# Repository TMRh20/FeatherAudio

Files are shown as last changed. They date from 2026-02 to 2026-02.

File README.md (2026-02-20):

# FeatherAudio
Custom Circuit Board for Feather 52840

Designed by TMRh20, Sponsored by [PCBWay](https://pcbway.com)
<br>
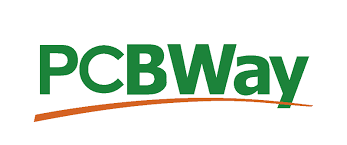
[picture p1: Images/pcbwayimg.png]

<br><br>
Requirements:<br>
2 x Custom Circuit Board <br>
2 x Feather 52840 based board (Feather 52840 Sense or Express) <br>
2 x Max98357A I2S Amplifier breakout <br>
2 x 4 to 8 Ohm Speaker (Gikfun 1.5" 4-Ohm, 3w, EK1794) <br>
2 x 2032 3.3v Coin Battery <br>
6 x AAA Battery <br>
(Optional) 2 x Micro-SD Card <br>
<br>
This custom circuit board was designed for basic prototyping via the AutoAnalogAudio library, however, it can be used
to create a custom walkie-talkie or intercom with range similar to Bluetooth. <br>

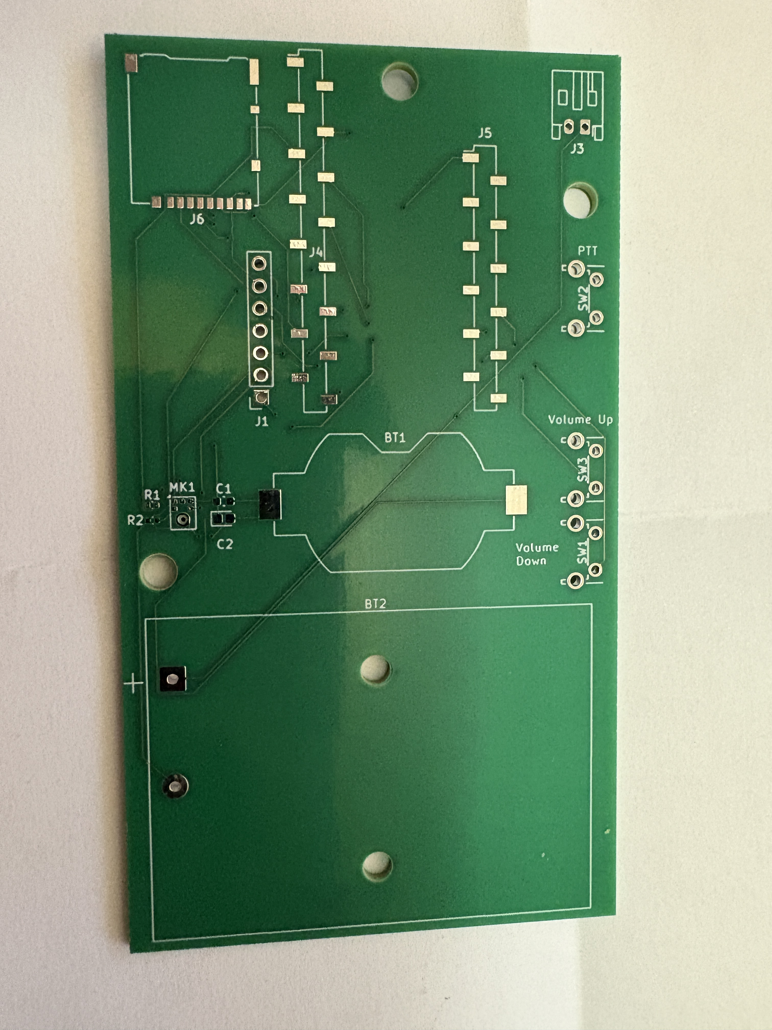
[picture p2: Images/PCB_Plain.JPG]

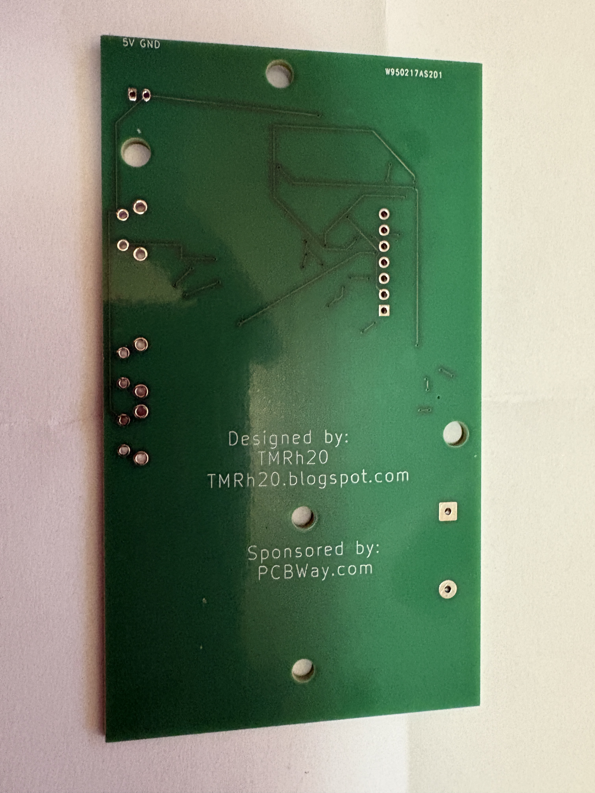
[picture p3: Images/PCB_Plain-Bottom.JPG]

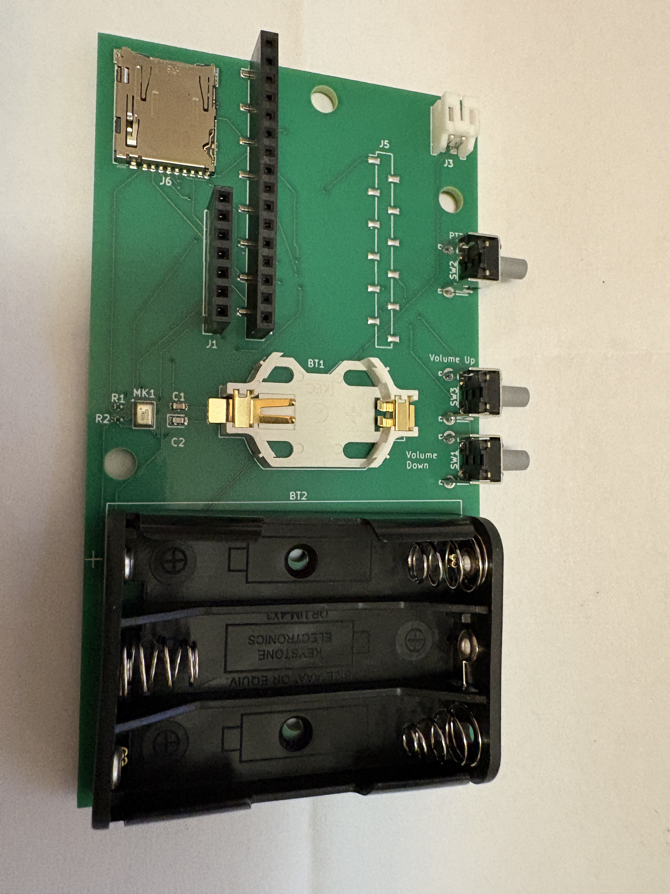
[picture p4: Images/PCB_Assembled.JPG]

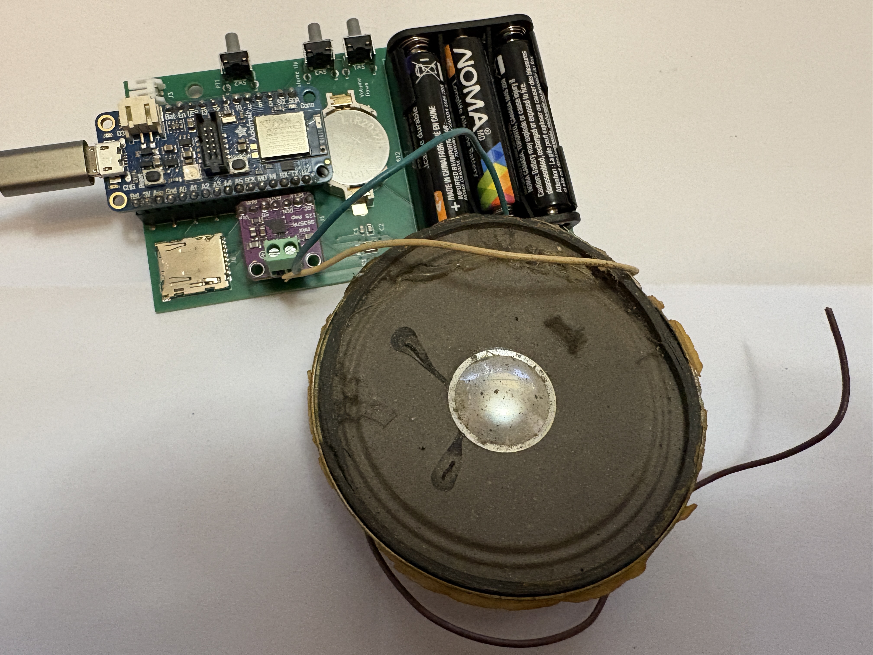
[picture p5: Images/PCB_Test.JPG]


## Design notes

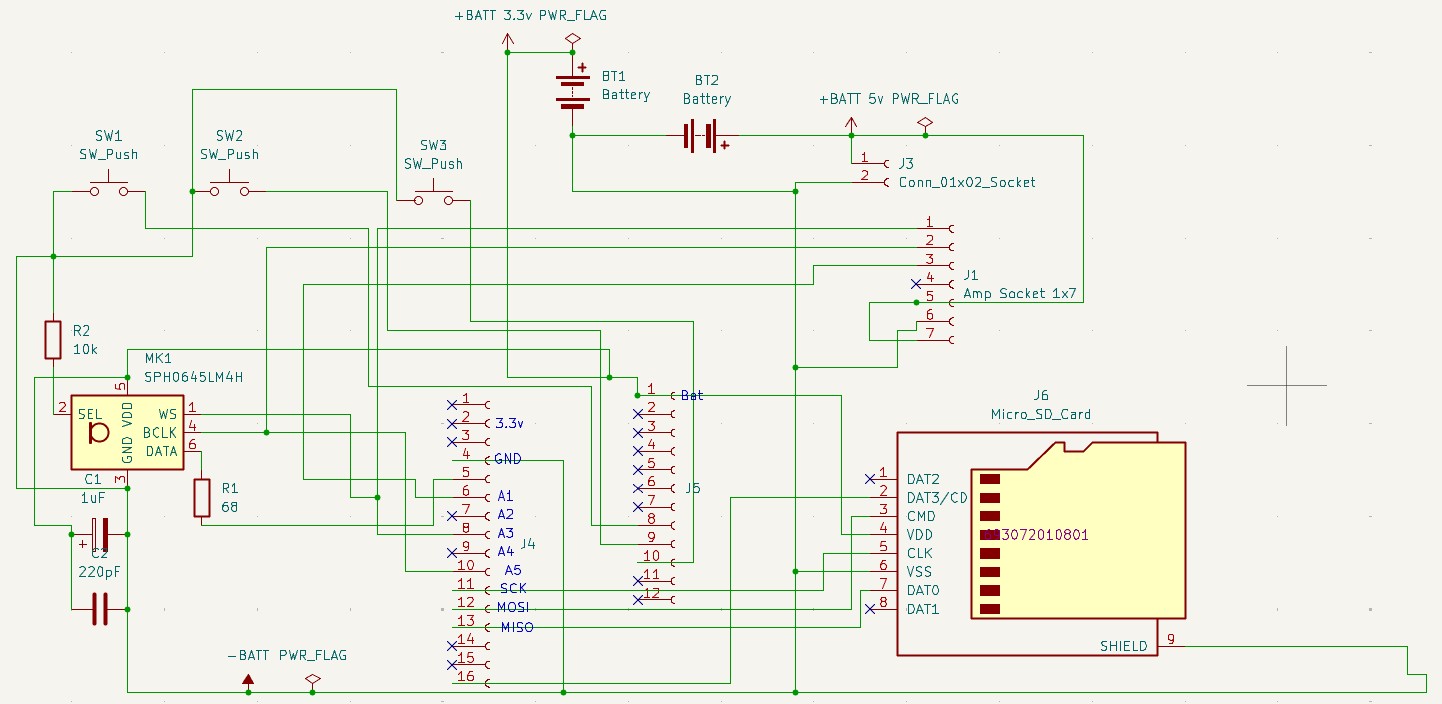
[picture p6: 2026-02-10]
Images/Schematic.jpg

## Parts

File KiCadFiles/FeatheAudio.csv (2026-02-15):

Reference | Qty | Value | DNP | Exclude from BOM | Exclude from Board | Footprint | Datasheet | Description | # | Part Number
BT1 | 1 | Battery |  |  |  | Battery:BatteryHolder_Keystone_1058_1x2032 | ~ | Holder Battery; Coin Battery; 1 Cell; Tab; Glass Filled LCP; 0.787 in. Dia. | 1 | 1058
BT2 | 1 | Battery |  |  |  | Battery:BatteryHolder_Keystone_2479_3xAAA | ~ | Cylindrical Battery Contacts, Clips, Holders & Springs 3AAA HOLDER PC MNT | 2 | 2479
C1 | 1 | 1uF |  |  |  | Capacitor_SMD:C_0603_1608Metric | ~ | 100V 1uF X7S å ¤10% 0805 Multilayer Ceramic Capacitors MLCC - SMD/SMT ROHS | 3 | GRM188D72A105KE01D（100V 1uF X7T 10% 0603）
C2 | 1 | 220pF |  |  |  | Capacitor_Tantalum_SMD:CP_EIA-1608-08_AVX-J | ~ | 0603 220 pF 50 V Â±1 % Tolerance C0G/NP0 SMT Multilayer Ceramic Chip Capacitor | 4 | VJ0603A221FXACW1BC
J1 | 1 | Amp Socket 1x7 |  |  |  | Connector_PinSocket_2.54mm:PinSocket_1x07_P2.54mm_Vertical | ~ | Btb Conn, Rcpt, 7Pos, 1Row, 2.54Mm Rohs Compliant: Yes |Wurth Elektronik 61300711821 | 5 | 61300711821
J3 | 1 | Conn_01x02_Socket |  |  |  | Connector_JST:JST_PH_S2B-PH-K_1x02_P2.00mm_Horizontal | ~ | Conn Shrouded Header (4 Sides) HDR 2 POS 2mm Solder RA Side Entry Thru-Hole Box | 6 | S2B-PH-K-S(LF)(SN)
J4 | 1 | XIAO LEFT |  |  |  | Connector_PinSocket_2.54mm:PinSocket_1x16_P2.54mm_Vertical_SMD_Pin1Left | ~ | THT Vertical Socket Header WR-PHD, Pitch 2.54 mm, Single Row, 16 pins | 7 | DS1023-16-1*16B81XBX1 work? https://www.tme.eu/en/details/ds1023-16-1x16tx1/pin-headers/connfly/ds1023-16-1-16b81xbx1/
J5 | 1 | XIAO RIGHT |  |  |  | Connector_PinSocket_2.54mm:PinSocket_1x12_P2.54mm_Vertical_SMD_Pin1Left | ~ | THT Vertical Socket Header WR-PHD, Pitch 2.54 mm, Single Row, 12 pins | 8 | 4217-CSHC121-1202A001C1AC-ND https://www.greenconn.com/Upload/Products/drawing-cshc121.pdf
J6 | 1 | Micro_SD_Card |  |  |  | Connector_Card:microSD_HC_Hirose_DM3AT-SF-PEJM5 | https://www.we-online.com/components/products/datasheet/693072010801.pdf | Conn, Memory Skt, Microsd, 8POS, Hinged Rohs Compliant: Yes | 9 | 693072010801
MK1 | 1 | SPH0645LM4H |  |  |  | Sensor_Audio:Knowles_SPH0645LM4H-6_3.5x2.65mm | https://www.knowles.com/docs/default-source/default-document-library/sph0645lm4h-1-datasheet.pdf | Knowles MEMS Microphone, 24-bit I2S, 65 dBA SNR, LGA-6 | 10 | SPH0645LM4H-1-8
R1 | 1 | 68 |  |  |  | Resistor_SMD:R_0402_1005Metric | ~ | Res Thick Film 2512 68 Ohm 5% 3W Â±200ppm/C Pad SMD T/R Automotive | 11 | FRC0402J680 TS（68R 5% 62.5mW 0402）
R2 | 1 | 10k |  |  |  | Resistor_SMD:R_0402_1005Metric | ~ | Precision resistor, SMD [TE Connectivity] SMF310KJT Precision resistor, SMD | 12 | RC0402FR-0710KL（0402 10K 1%）
SW1,SW2,SW3 | 3 | SW_Push |  |  |  | Button_Switch_THT:SW_Tactile_SPST_Angled_PTS645Vx83-2LFS | Switch Tactile N.O. SPST Round Button PC Pins 0.05A 12VDC 100000Cycle 1.96N Thru-Hole Bulk,~ | Switch Tactile N.O. SPST Round Button PC Pins 0.05A 12VDC 100000Cycle 1.96N Thru-Hole Bulk | 13 | Y97HS12A4VAFP

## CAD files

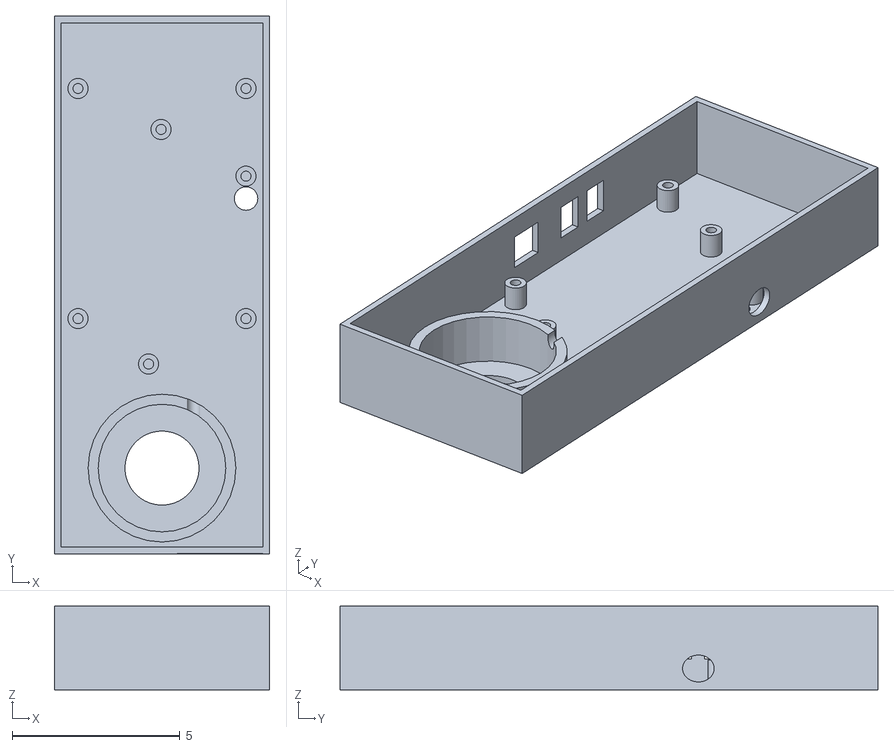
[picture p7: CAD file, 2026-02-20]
3D-Case/FeatherBaseV1.stl
6.40 x 16.0 x 2.50

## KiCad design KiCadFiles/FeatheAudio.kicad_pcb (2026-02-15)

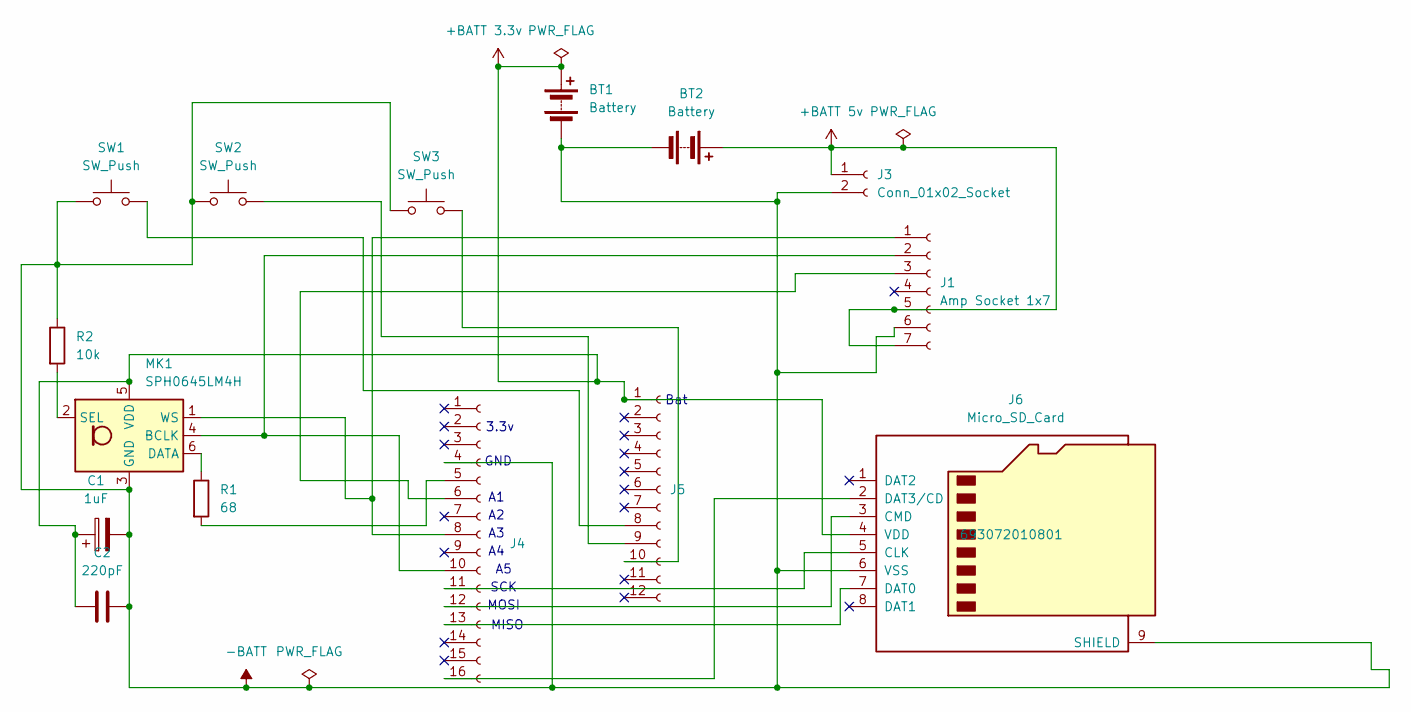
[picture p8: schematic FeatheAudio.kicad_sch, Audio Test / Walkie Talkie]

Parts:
BT1: Battery; BatteryHolder_Keystone_1058_1x2032; Part Number 1058
BT2: Battery; BatteryHolder_Keystone_2479_3xAAA; Part Number 2479
C1: 1uF; C_0603_1608Metric; Part Number GRM188D72A105KE01D（100V 1uF X7T 10% 060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
C2: 220pF; CP_EIA-1608-08_AVX-J; Part Number VJ0603A221FXACW1BC
J1: Amp Socket 1x7; PinSocket_1x07_P2.54mm_Vertical; Part Number 61300711821
J3: Conn_01x02_Socket; JST_PH_S2B-PH-K_1x02_P2.00mm_Horizontal; Part Number S2B-PH-K-S(LF)(SN)
J4: XIAO LEFT; PinSocket_1x16_P2.54mm_Vertical_SMD_Pin1Left; Part Number DS1023-16-1*16B81XBX1 work? https://www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
J5: XIAO RIGHT; PinSocket_1x12_P2.54mm_Vertical_SMD_Pin1Left; Part Number 4217-CSHC121-1202A001C1AC-ND https://ww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
J6: Micro_SD_Card; microSD_HC_Hirose_DM3AT-SF-PEJM5; Part Number 693072010801
MK1: SPH0645LM4H; Knowles_SPH0645LM4H-6_3.5x2.65mm; Part Number SPH0645LM4H-1-8
R1: 68; R_0402_1005Metric; Part Number FRC0402J680 TS（68R 5% 62.5mW 0402）
R2: 10k; R_0402_1005Metric; Part Number RC0402FR-0710KL（0402 10K 1%）
SW1, SW2, SW3: SW_Push; SW_Tactile_SPST_Angled_PTS645Vx83-2LFS; Part Number Y97HS12A4VAFP

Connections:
+BATT 3.3v: BT1.1 (+), C1.1, C2.1, J5.1, J6.4 (VDD), MK1.5 (VDD)
+BATT 5v: BT2.1 (+), J1.5, J1.7, J3.1
-BATT: BT1.2 (-), BT2.2 (-), C1.2, C2.2, J1.6, J3.2, J4.4, J6.6 (VSS), J6.9 (SHIELD), MK1.3 (GND), R2.1, SW1.1, SW2.1, SW3.1
unnamed: J1.1, J4.8, MK1.1 (WS)
unnamed: J1.2, J4.10, MK1.4 (BCLK)
unnamed: J1.3, J4.6
unnamed: J4.5, R1.2
unnamed: J4.11, J6.5 (CLK)
unnamed: J4.12, J6.3 (CMD)
unnamed: J4.13, J6.7 (DAT0)
unnamed: J4.16, J6.2 (DAT3/CD)
unnamed: J5.8, SW1.2
unnamed: J5.9, SW2.2
unnamed: J5.10, SW3.2
unnamed: MK1.6 (DATA), R1.1
unnamed: MK1.2 (SEL), R2.2

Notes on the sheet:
3.3v
MISO
SCK
GND
Bat
MOSI

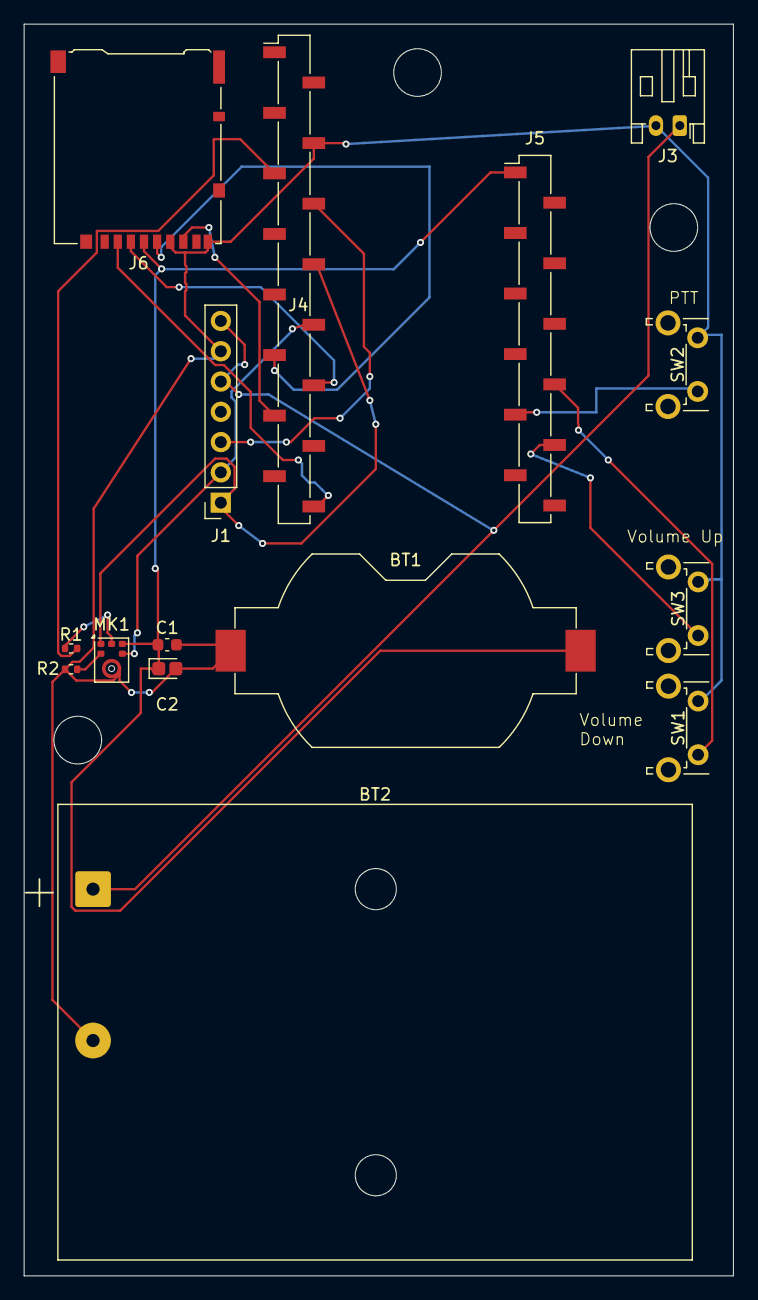
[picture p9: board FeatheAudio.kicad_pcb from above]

Board: 2 copper layers, 59.5 x 105.0 mm, 15 parts (0 on the bottom side), 16 nets.

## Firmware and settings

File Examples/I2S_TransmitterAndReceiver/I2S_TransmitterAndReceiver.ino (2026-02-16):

/** 
* Wireless Audio Transceiver
*
* This code allows users to create a wireless radio or intercomm using the custom PCB
* found at https://github.com/TMRh20/FeatherAudio
* 
* by TMRh20 2026
*/



#include <AutoAnalogAudio.h>
#include <nrf_to_nrf.h>

AutoAnalog aaAudio;
nrf_to_nrf radio;


#if defined(USE_TINYUSB)
// Needed for Serial.print on non-MBED enabled or adafruit-based nRF52 cores
#include "Adafruit_TinyUSB.h"
#endif

/**************** USER VARIABLES *************************/

#define AUDIO_DEBUG 1                // Set to 1 to print out values from the microphone
#define RADIO_CHANNEL 50             // Set the channel for the radio
volatile float volumeControl = 3.5;  // Default Volume level
uint32_t sampleRate = 32000;         // Either 16000 or 32000 supported

/*********************************************************/

#define BUFFER_SIZE 124
uint8_t address[6] = { "1Node" };
volatile bool micActive = false;
volatile bool rxToggled = false;
volatile bool txToggled = false;

/*****************************************/

void volUp() {
  volumeControl += 0.5;         // Raise Volume
  if (digitalRead(9) == LOW) {  // If both pins are pressed, volDown pressed first
    micActive = true;           // Enable the microphone until PTT is pressed
    setupInput();               // Setup audio for the microphone
  }
}
/*****************************************/
void volDown() {
  volumeControl -= 0.5;       // Lower volume
  if (volumeControl < 0.1) {  // If volume setting too low set to 0.0
    volumeControl = 0.0;
  }
}

/*****************************************/

void ptt() {

  if (digitalRead(6) == LOW) {  // If PTT button pressed
    micActive = true;           // Enable I2S microphone
    rxToggled = true;           // Only enable microphone once via this variable

  } else {
    micActive = false;  // Enable I2s amplifier output
    txToggled = true;   // Only enable output once via this variable
  }
}

/*****************************************/

void setupOutput() {
  aaAudio.manualI2S = false;             // Use internal I2S timers for I2S
  aaAudio.begin(0, 2);                   // Setup aaAudio using I2S amplifier output
  aaAudio.dacBitsPerSample = 16;         // 16-bit samples output to I2S
  aaAudio.setSampleRate(sampleRate, 0);  // 32 or 16kHz
  radio.startListening();                // Start the radio in listen mode
}

/*****************************************/

void setupInput() {
  aaAudio.manualI2S = true;              // Use PWM to drive the I2S signal
  aaAudio.begin(2, 0);                   // Enable I2S microphone input
  aaAudio.adcBitsPerSample = 24;         // Needs to be 24 bits for the onboard microphone
  aaAudio.setSampleRate(sampleRate, 0);  // 32 or 16kHz
  radio.stopListening();                 // Start the radio in tx mode
}

/*****************************************/

void setup() {

  Serial.begin(115200);
  radio.begin();  // General radio config
  radio.setChannel(RADIO_CHANNEL);
  radio.setPayloadSize(BUFFER_SIZE);
  radio.setAutoAck(0);
  radio.setDataRate(NRF_1MBPS);
  radio.openWritingPipe(address);
  radio.openReadingPipe(1, address);
  radio.startListening();

  pinMode(LED_BUILTIN, OUTPUT);  // LED toggles to red when data is received, off if no data
  digitalWrite(LED_BUILTIN, LOW);
  pinMode(6, INPUT_PULLUP);  // Enable PTT pin
  attachInterrupt(digitalPinToInterrupt(6), ptt, CHANGE);
  pinMode(9, INPUT_PULLUP);
  pinMode(5, INPUT_PULLUP);
  attachInterrupt(digitalPinToInterrupt(9), volDown, FALLING);  // Enable Volume pins
  attachInterrupt(digitalPinToInterrupt(5), volUp, FALLING);

  aaAudio.I2S_PIN_LRCK = 28;                // WS Pin: On the Feather 52840 Express or Sense, this is pin A3
  aaAudio.maxBufferSize = BUFFER_SIZE * 2;  // Set maxBufferSize to limit memory usage
  setupOutput();                            // Setup I2S audio output
}

/*****************************************/

int32_t audioBuffer[BUFFER_SIZE / 2];
uint32_t lastRadio = millis();

/*****************************************/

void loop() {

  if (micActive) {    // If the mic has been toggled on by the PTT or combination of LowVolume then HighVolume buttons
    if (rxToggled) {  // Only do this once per toggle
      setupInput();   // Configure I2S audio input
      rxToggled = false;
    }
    aaAudio.getADC(BUFFER_SIZE / 2);  // Get data from I2S mic, will get 18-bit samples in a 32-bit format, but output 16-bit samples over the radio

    uint16_t counter2 = 0;
    for (int i = 0; i < BUFFER_SIZE / 2; i++) {
      memcpy(&audioBuffer[i], &aaAudio.adcBuffer16[counter2], 4);  // Loop to copy data from 16-bit incoming buffer to a 32-bit integer buffer
      audioBuffer[i] >>= 2;                                        // Change from 18-bit to 16-bit
      memcpy(&aaAudio.dacBuffer16[i], &audioBuffer[i], 2);         // Copy to 16-bit output buffer from 32-bit format
      counter2 += 2;
    }
#if AUDIO_DEBUG > 0
    int16_t test = 0;
    memcpy(&test, &aaAudio.dacBuffer16[0], 2);
    Serial.print(test);
    Serial.print(",");
    Serial.print(-5000);
    Serial.print(",");
    Serial.println(5000);
#endif
    radio.startWrite(&aaAudio.dacBuffer16[0], BUFFER_SIZE, 1);  // Send 62 16-bit samples over the radio (124 bytes)

  } else {

    if (txToggled) {      // If I2S output has been toggled
      setupOutput();      // Setup I2S amplifier output
      txToggled = false;  // Only needs to be done once
    }
    if (radio.available()) {  // Check for incoming radio data

      radio.read(&aaAudio.dacBuffer16[0], BUFFER_SIZE);  // Read incoming radio data, 124 bytes or 62 16-bit samples

      for (int i = 0; i < BUFFER_SIZE / 2; i++) {  // Loop for the number of actual samples
        int16_t test = aaAudio.dacBuffer16[i];     // Adjust volume for incoming data
        test *= volumeControl;
        aaAudio.dacBuffer16[i] = test;
      }
#if AUDIO_DEBUG > 0
      int16_t sampleOut = 0;
      memcpy(&sampleOut, &aaAudio.dacBuffer16[0], 2);
      Serial.print(sampleOut);  // Print one sample from each batch if data received & debug enabled
      Serial.print(",");
      Serial.print(-10000);
      Serial.print(",");
      Serial.println(10000);
#endif
      aaAudio.feedDAC(0, BUFFER_SIZE / 2);  // Feed the I2S amplifier with the actual number of samples
      lastRadio = millis();                 // Timer to silence the radio & toggle the LED off/on
      digitalWrite(LED_BUILTIN, HIGH);      // Toggle red LED on
    } else {
      if (millis() - lastRadio > 100) {  // If no data for 100ms
        aaAudio.disableDAC();
        digitalWrite(LED_BUILTIN, LOW);  // Turn off the red LED
      }
    }
  }
}

/*****************************************/

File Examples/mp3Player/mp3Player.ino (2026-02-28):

/*
* Requires https://github.com/TMRh20/microDecoder library
*/

#include <SD.h>
#include <AutoAnalogAudio.h>
#include "mp3.h"  // decoder
#include "pcm.h"

mp3 MP3;
pcm audio;
AutoAnalog aaAudio;


/************ USER CONFIGURATION ***************/
const char* audioFilename = "noceil.mp3";
uint8_t SD_CS_PIN = 2;  // Set this to your CS pin for the SD card/module

float volumeControl = 0.2;
#define AUDIO_BUFFER_SIZE 1600  // Should be a multiple of 64
/**********************************************/

void setup() {

  Serial.begin(115200);
  while (!Serial) delay(10);

  Serial.print("Init SD card...");
  if (!SD.begin(SD_CS_PIN)) {
    Serial.println("init failed!");
    return;
  }
  Serial.println("SD init ok");

  aaAudio.I2S_PIN_LRCK = 28;  // Use different LRCK pin for Feather Express 52840
  aaAudio.maxBufferSize = AUDIO_BUFFER_SIZE;
  aaAudio.begin(0, 2);

  playAudio(audioFilename);
}

void loop() {

  loadBuffer();

  // Control via Serial for testing
  if (Serial.available()) {
    char c = Serial.read();
    if (c == '=') {
      volumeControl += 0.1;
    } else if (c == '-') {
      volumeControl -= 0.1;
      volumeControl = max(0.0, volumeControl);
    } else if (c == 'p') {
      playAudio("atliens.mp3");
    } else if (c == 'c') {
      playAudio("dopeBoys.mp3");
    }
    Serial.println(volumeControl);
  }
}


File myFile;

void playAudio(const char* audioFile) {

  MP3.end();
  if (myFile) {
    myFile.close();
  }
  aaAudio.disableDAC();

  //Open the designated file
  myFile = SD.open(audioFile);

  if (myFile) {
    MP3.begin(myFile);
    MP3.getMetadata();
    aaAudio.setSampleRate(MP3.Fs, 1);
    Serial.println(MP3.Fs);
    aaAudio.dacBitsPerSample = MP3.bitsPerSample;
    Serial.println(MP3.bitsPerSample);
  }else{
    Serial.println("Failed to open file");
  }
}

void loadBuffer() {

  uint32_t sampleCounter = 0;
  if (myFile.available() >= AUDIO_BUFFER_SIZE) {
    for (uint32_t i = 0; i < AUDIO_BUFFER_SIZE / 64; i++) {
      audio = MP3.decode();
      memcpy(&aaAudio.dacBuffer16[sampleCounter], audio.interleaved, 128);  // 128 bytes
      sampleCounter += 64;                                                  // 64 samples per go
    }
    for (uint32_t i = 0; i < AUDIO_BUFFER_SIZE; i++) {
      int16_t sample = aaAudio.dacBuffer16[i];
      sample *= volumeControl;
      aaAudio.dacBuffer16[i] = sample;
    }
    aaAudio.feedDAC(0, sampleCounter);
  } else {
    aaAudio.disableDAC();
  }
}

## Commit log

2026-02-10 FeatherAudio PCB First Commit
    [FeatheAudio-B_Cu.gbr, FeatheAudio-B_Mask.gbr, FeatheAudio-B_Paste.gbr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]
2026-02-15 Update J5 part number & BOM
    [FeatheAudio.csv, FeatheAudio.kicad_pcb, FeatheAudio.kicad_sch]
2026-02-16 Update I2S_TransmitterAndReceiver.ino
    - Cleaner debug prints in the Serial Plotter
    - Disable DAC instead of feeding it 0s
    - Adjust volume control var
2026-02-20 Add v1 3D-Print for base
    [FeatherBaseV1.stl]
